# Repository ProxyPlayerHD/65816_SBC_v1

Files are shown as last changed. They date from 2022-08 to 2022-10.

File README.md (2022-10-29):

# 65816_SBC_v1
My personal 65816 based SBC, Designed to be easy to expand!

# Files
the Repo contains everything necessary to order, build, and program your own SBC.

* KiCad  
This folder contains the Schematic, PCB, and Gerber files
* Logic  
This folder contains the Decoding Logic for the CPLD, [Digital](https://github.com/hneemann/Digital) is used to open the .dig files
* Code  
This folder contains the BIOS Code and some basic Assembly and C environments that can be used to write programs for the SBC

# System Info

* CPU: 65c816 (tested up to 20MHz)
* RAM: 1MB of onboard SRAM
* ROM: 16kB of onboard FLASH
* IO: FT240X, 65c22 (VIA), PS/2 Port for both Mouse and Keyboard, Expansion Connector

# Memory/IO Map:

|  Start | End | Name  | Size |
| --- | --- | ----- | --- |
| 0x000000 | 0x00FDFF | LoRAM |  63.5 kB |
| 0x00FF00 | 0x00FFFF | LoROM |  256.0 B |
| 0x010000 | 0x0100FF | IO |  256.0 B |
| 0x010100 | 0x013FFF | HiROM | 15.75 kB |
| 0x014000 | 0x0FFFFF | HiRAM | 944.0 kB |
| 0x100000 | 0xFFFFFF | EXT |  15.0 MB |

| Address  | Name | Mini Description |
| --- | --- | --- |
| 0x010000 | CTRL | CPLD Internal Control Register |
| 0x010001 | FT240X | 8-bit UART that connects over USB |
| 0x010002 | LFSR | CPLD Internal Random Number Generator |
| 0x01001x | VIA | 65c22 Timer/GPIO Chip, covers 16 Addresses |

Writing to CTRL:  
7 - x
6 - x
5 - x
4 - x
3 - x
2 - Enable External Interrupts
1 - Enable Timer Interrupt
0 - Enable VIA Interrupts

Reading from CTRL:  
7 - FTDI RXF (0 = Data can be read to FIFO)
6 - FTDI TXE (0 = Data can be written from FIFO)
5 - 0
4 - 0
3 - 0
2 - External Interrupt Enabled? (0 = No, 1 = Yes)
1 - Timer Interrupt Enabled? (0 = No, 1 = Yes)
0 - VIA Interrupt Enabled? (0 = No, 1 = Yes)

# ROM Weirdness
the FLASH Chip is a bit strangely mapped.

LoROM sits directly next to HiROM in the CPU's Memory Map. But in the FLASH Chip both sections are actually quite far apart.

This is because only 64kB of the FLASH is accessible, meaning it only sees the lower 16 Address Lines. so when the CPU Reads from Address 0x00FF00 (Start of LoROM) is does actually Access Address 0x00FF00 in the ROM. but when the CPU Reads from Address 0x010000 (Start of HiROM) the ROM cannot see the upper 8-bits and therefore sees it as 0x000000.

so in short, HiROM is mapped (in the ROM) to 0x000000 - 0x003FFF, while LoROM is mapped (in the ROM) to 0x00FF00 - 0x00FFFF.

the BIOS_65816.cfg for ca65 handles this automatically when assembling the BIOS

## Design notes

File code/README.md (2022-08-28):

# Code
This Folder has the BIOS Code, and both basic Assembly/C environments

for Assembly ca65 from the [cc65 C Compiler Utility](https://github.com/cc65/cc65) was used. And for the C environment, [Calypsi C](https://www.calypsi.cc/) is used.

# Files

* BIOS  
    * BIOS.a816 - the Assembly file containg the ROM Code
    * BIOS.bin - a premade binary file in case you don't want to Assemble your own
    * BIOS_816.cfg - the ca65 Config file used for Linking
    * SBC.inc - an Include file for ca65 that defines some constants specifically for the SBC
* ca65-env
    * exehdr.a816 - the Assembly file containing the Header for the output file
    * exehdr.o - a premade Object file so you don't need to assemble it yourself
    * SBC_816.cfg - the ca65 Config file used for Linking (different from the BIOS)
    * test.a816 - a template Assembly file to write your own code with!
* CalypsiC-env
    * cstartup.s - The Assembly file containing the startup code for the C environment
    * cstartup.o - a premade Object file so you don't need to assemble it yourself
    * MemAccess.h - a C Header file containing basic Memory Accessing and bit manipulation Functions
    * SBC.h - a C Header file containing some define's for SBC specific constants like Memory Addresses
    * SBC_816.scm - the LN65816 Config file used for Linking
    * stdio_functions.c - a C file containing the functions needed for "printf" and such to work
    * stdio_functions.o - a premade Object file so you don't need to assemble it yourself
    * test.c - a template C file to write your own code with!

# Commands to make everything work
This assumes your system has cc65 and Calypsi C installed and that all necessary files are located in the same Directory

Assembling and Linking the BIOS Assembly file:

```
CA65 --cpu 65816 -I Include -l BIOS.lst -o BIOS.o BIOS.a816
LD65 -v -o BIOS.bin -C BIOS_816.cfg BIOS.o
```

Assembling and Linking the example Assembly file:

```
CA65 --cpu 65816 -l test.lst -o test.o test.a816
LD65 -v -o test.pgz -C SBC_816.cfg exehdr.o test.o
```

Compiling and Linking the example C file:

```
CC65816 --64bit-doubles --code-model large --data-model large -I Include -O2 --list-file test.lst -o test.o test.c
LN65816 --hosted --cross-reference --rtattr cstartup=SBCv1 --verbose --output-format pgz -o test.pgz SBC_816.scm cstartup.o stdio_functions.o test.o clib-lc-ld-double64.a
```

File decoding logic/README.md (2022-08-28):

# Decoding Logic
This Folder has the entire Logic for the CPLD

My workflow is a bit strange:

* The Circuit was designed and exported to Verilog using [Digital](https://github.com/hneemann/Digital)
* Quartus II (the free one) was then used to assign the pins and Synthesize the entire thing (MAX7064 = ATF1508)
* POF2JED was used to convert the POF file generated by Quartus to a JED file
* and finally, ATMISP was used to actually program the CPLD using the JED file

this process works surprisingly well.

# Files

* CPLD-MAIN.dig  
the main file containing the Bulk of the Logic, Quartus needs to be told that "CPLD-MAIN" is the top module
* CPLD-MAIN.jed  
a premade JED file, in case you don't want to go through the whole process of making your own
* latch.dig
* latch8.dig
* LFSR.dig  
Seperate files for the Latching and RNG Circuits, as an attempt to keep the mess of the main file smaller

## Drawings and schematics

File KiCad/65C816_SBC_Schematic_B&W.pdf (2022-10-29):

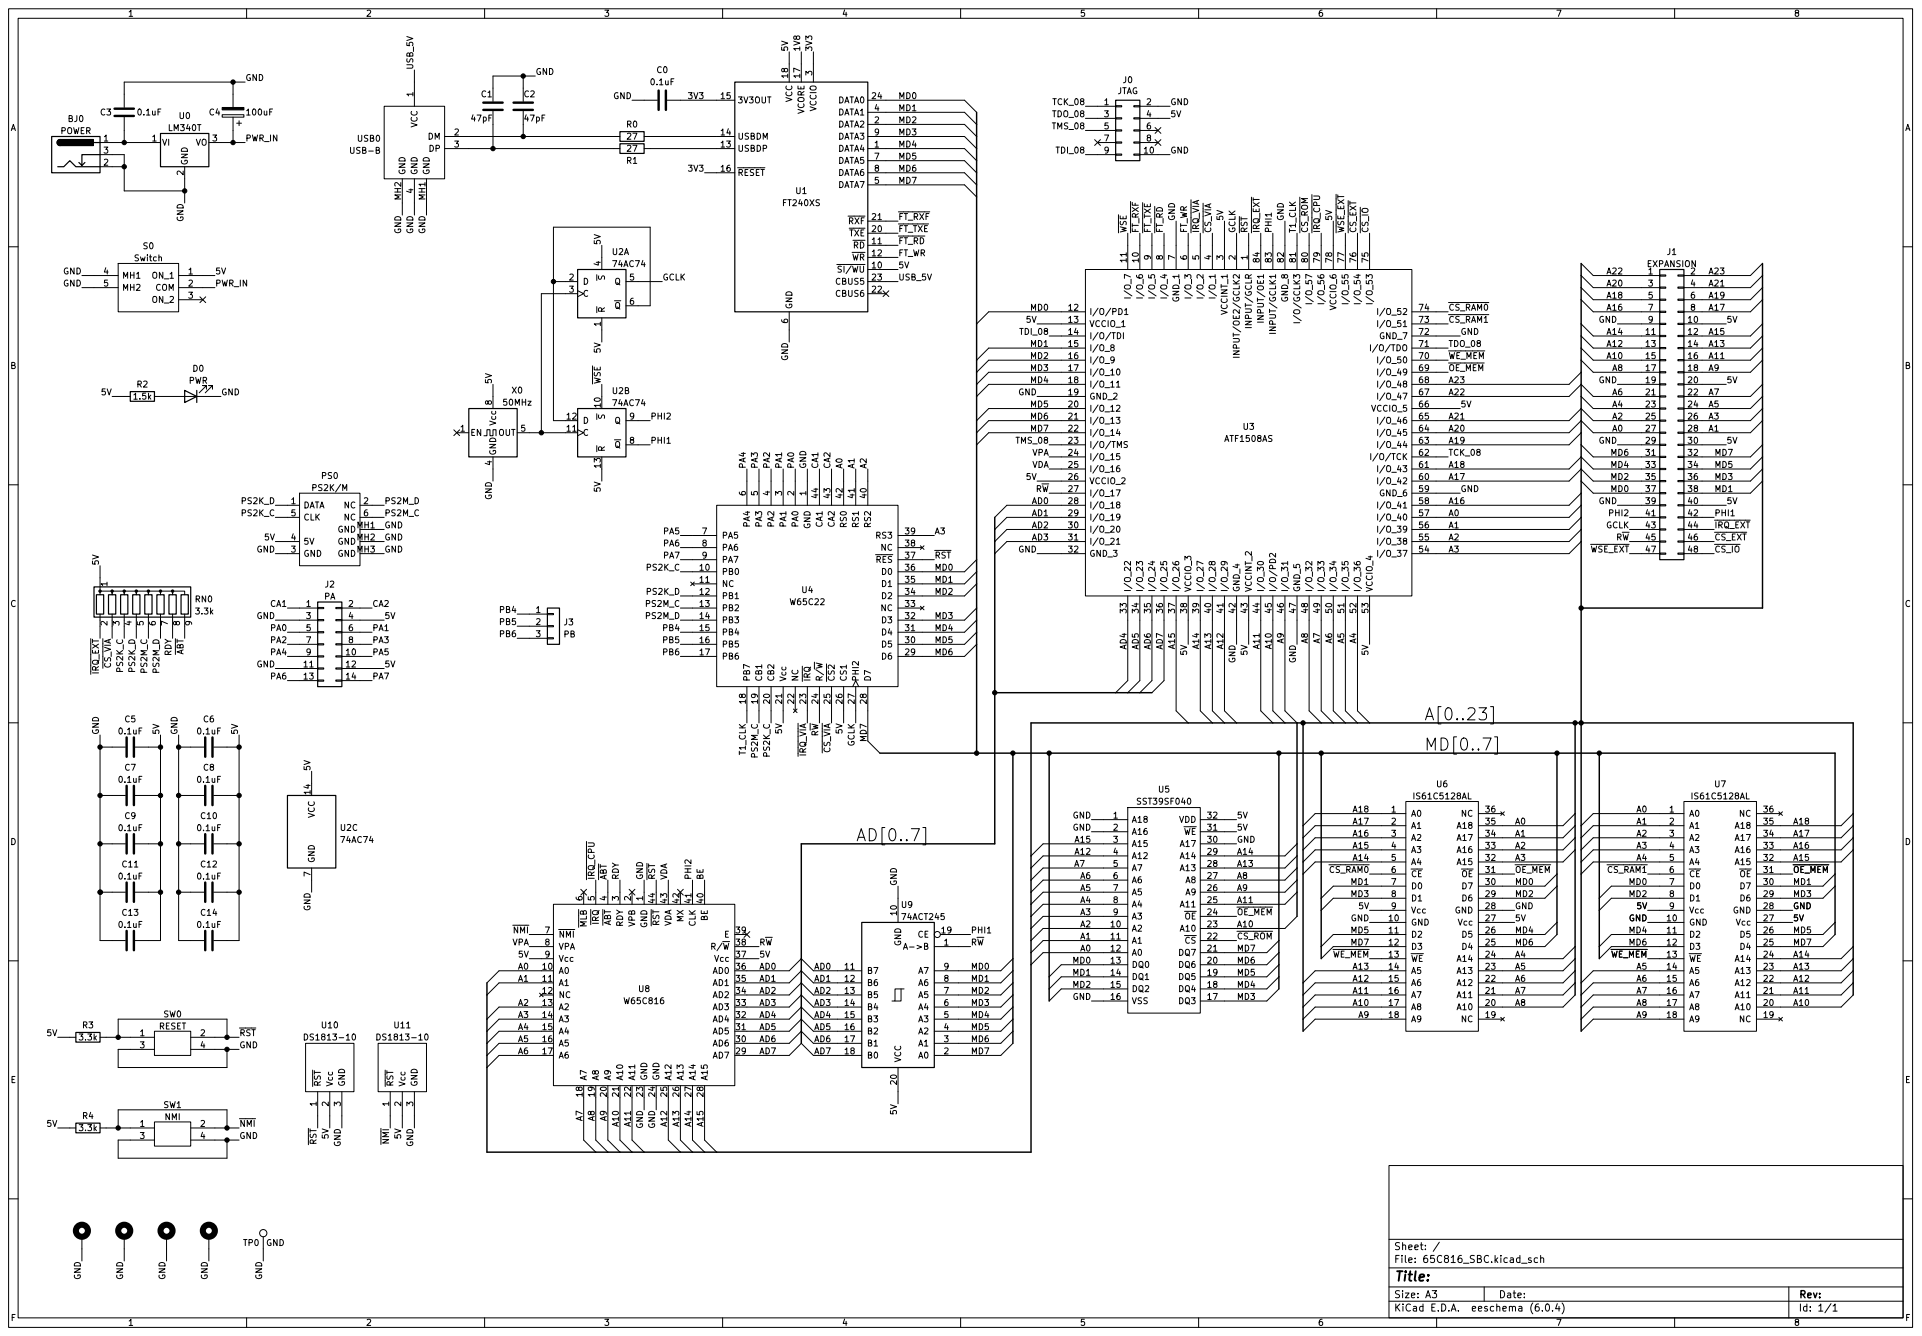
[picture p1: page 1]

4 BE 40 CLK 41 MX 42 VDA 43 ~{RST} 44 ~{IRQ} 5 ~{MLB} 6 ~{NMI} 7 VPA 8 Vcc 9 U8 W65C816

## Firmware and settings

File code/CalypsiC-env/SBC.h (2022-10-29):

#ifndef __SBC
	#define __SBC
	
	#define _CTRL			0x010000
	#define _SERIAL			0x010001
	#define _LSFR			0x010002
	#define _VIA_ORB		0x010010
	#define _VIA_ORA		0x010011
	#define _VIA_DDRB		0x010012
	#define _VIA_DDRA		0x010013
	#define _VIA_T1CL		0x010014
	#define _VIA_T1CH		0x010015
	#define _VIA_T1LL		0x010016
	#define _VIA_T1LH		0x010017
	#define _VIA_T2CL		0x010018
	#define _VIA_T2CH		0x010019
	#define _VIA_SR			0x01001A
	#define _VIA_ACR		0x01001B
	#define _VIA_PCR		0x01001C
	#define _VIA_IFR		0x01001D
	#define _VIA_IER		0x01001E
	#define _VIA_ORANH		0x01001F
	
	#define _VIA_T1C16		0x010014
	#define _VIA_T1L16		0x010016
	#define _VIA_T2C16		0x010018
	
	#define _BIT_TXE		0b01000000
	#define _BIT_RXF		0b10000000
	
	// Software SPI over the VIA
	#define _SPI_IDLE		0b00000100	// Default IO State when nothing is happening
	#define _SPI_SCK		0b00000001
	#define _SPI_MOSI		0b00000010
	#define _SPI_SS			0b00000100
	#define _SPI_MISO		0b10000000
	
	#define _CTRL_VIAI		0b00000001	// VIA Interrupt bit mask
	#define _CTRL_T1I		0b00000010	// 50x T1 Interrupt bit mask
	#define _CTRL_EXI		0b00000100	// External Interrupt bit mask
	
	
	
	#define rnd()			*((uint8_t*)_LSFR)
	#define termcolor(R,G,B) printf("\x1B[38;2;%u;%u;%um", (uint8_t)R, (uint8_t)G, (uint8_t)B);
	//#define termcolor(X,Y,Z) printf("\x1B[38;2;");printf("%d", (uint8_t)X);printf(";");printf("%d", (uint8_t)Y);printf(";");printf("%d", (uint8_t)Z);printf("m")
	#define termreset() printf("\x1B[39m")
	#define cls() printf("\x1B[2J")
	
#endif
